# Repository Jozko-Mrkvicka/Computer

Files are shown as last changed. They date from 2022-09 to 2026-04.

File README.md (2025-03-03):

HALUŠKA 9000
============
This is a simulation of very simple 16-bit computer based on logic gates implemented in Matlab/Simulink.
Computer has CPU with 29 instructions, memory consists of 4KB ROM (instructions), 4KB RAM, 1KB video memory, and 4KB of data ROM.
input unit (simple numeric keyboard) and output display (8x16 pixel resolution). To demonstrate
its capabilities there is Snake game hardcoded in ROM.

!!!Please note that this is not the final version, project is still under development!!!

How to run 
----------
- Switch Matlab path to the Computer folder.

- From Matlab command line run the following commands:
    - "Run_Unit_Tests"                            - to check all libraries.
    - "Run_System_Tests"                          - to check high level functionalities.
    - "Compile ROM_Test_UART_Tx"                  - to build binary image of an application.
    - "Flash CODE ROM_Test_UART_Tx_Code 0x0000"   - to program instruction memory from address 0 with the compiled image.
    - "Flash CONST ROM_Test_UART_Tx_Const 0x0000" - to program constant data memory from address 0 with the compiled image.
    - "Computer"                                  - to open computer model.

- In Simulink window click on "play" button to run (or step) simulation.

- From Matlab command line run the following commands:
    - "FrontPanel" - to open front panel debugging/control window.
    - "DataMemory" - to open data memory debugging/control window.

    In file ROM.m there is placed assembly ROM code (firmware) which will be executed after "power on"
(after pressing Run button in Simulink window). This assembly code must be "compiled" to binary
before execution. The assembly code is placed in matlab array in the double format (default matlab format
for storing numeric data). During "compilation" the assembly code is converted to uint16_t format
and can be executed. To compile the code execute ROM.m file from Matlab command line (>> ROM).
You will see compiled binary code in uint16_t format as well as in uint8_t format (MSB/LSB) and also
original assembly code (for your convenience, handy for debugging/crosschecking). 

NOTE: If you forget to "compile" and you try to run the simulation then you will see the following error
message:
    Invalid setting in 'Computer/Memory/32B_ROM_Memory(Addr 0..15)/Byte_00' for parameter 'Value'.
    Caused by:
    Error evaluating parameter 'Value' in 'Computer/Memory/32B_ROM_Memory(Addr 0..15)/Byte_00'
    Undefined function 'RomCode' for input arguments of type 'double'.

After successful "compilation" open the file Computer.slx and press the Run button. Simulation will start.

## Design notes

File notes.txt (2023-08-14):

#############################################
#                   Notes
#############################################
─ ━ │ ┃ ┄ ┅ ┆ ┇ ┈ ┉ ┊ ┋ ┌ ┍ ┎ ┏
┐ ┑ ┒ ┓ └ ┕ ┖ ┗ ┘ ┙ ┚ ┛ ├ ┝ ┞ ┟
┠ ┡ ┢ ┣ ┤ ┥ ┦ ┧ ┨ ┩ ┪ ┫ ┬ ┭ ┮ ┯
┰ ┱ ┲ ┳ ┴ ┵ ┶ ┷ ┸ ┹ ┺ ┻ ┼ ┽ ┾ ┿
╀ ╁ ╂ ╃ ╄ ╅ ╆ ╇ ╈ ╉ ╊ ╋ ╌ ╍ ╎ ╏
═ ║ ╒ ╓ ╔ ╕ ╖ ╗ ╘ ╙ ╚ ╛ ╜ ╝ ╞ ╟
╠ ╡ ╢ ╣ ╤ ╥ ╦ ╧ ╨ ╩ ╪ ╫ ╬ 
╔═══════╤══════╦════════╤═══════╗
║       │      ║        │       ║
╟───────┼──────╫────────┼───────╢
║       │      ║        │       ║
╠═══════╪══════╬════════╪═══════╣
║       │      ║        │       ║
║       │      ║        │       ║
║       │      ║        │       
╚═══════╧══════╩════════╧═══════╝

░▒▓│┤╡╢╖╕╣║╗╝╜╛┐└┴┬├─┼╞╟╚╔╩╦╠═╬╧╨╤╥╙╘╒╓╫╪┘┌█▄▌▐▀ 

#############################################
#              Mrkvicka 9000
#############################################
- Dokumentacia
    - Dokoncit README.
    - Vylestit instrukcie.

    - Mrkvicka 9000 Programmer`s Manual
        - PDF
        - Readme
        - Instructions
        - Demo examples

    - Mrkvicka 9000 Hardware Manual
        - PDF
        - Simulink model

- Hardware:
    - Rozsirit klavesnicu na 128 znakov ASCII (aby sa dala kreslit textova grafika).
    - Pridat na klavesnicu tlacitko SHIFT.
    - Dokoncit obrazovku/terminal.

    - Pridat instrukciu JGT (jump if greater than) kvoli instrukcii CMPI (nie je mozne pouzit instrukciu JLT vo vsetkych pripadoch - operandy sa nedaju prehodit).

    - Pridat timer.

    - Ochrana pamati / error detection:
        - Indikovat chybu ak je viacero kontrolnych signalov do MUXu aktivnych. Vystup poslat na FrontPanel.
        - Detekovat stack overflow/underflow.

    - Zjednodusit architekturu:
        - Nahradit vsetky typy enkoderov pomocou jedneho 16_to_4.
        - Zistit ci by pomohlo keby som nahradil vsetky multiplexory iba pomocou jedneho typu.

- GUI
    - FrontPanel
        - Pridat tlacitka RESET, RUN, STOP, STEP.
    - Pridat Instruction Memory Panel.
    - Pridat Terminal (obrazovka, klavesnica).

- Preprocessor:
    - Zarovnat pravy okraj vygenerovaneho kodu.

- Testy

- Firmware:
    - memcpy()
    - Tetris
    - Snake
    - Hodiny
    - Kalkulacka
    - Textovy editor

    - Faktorial -> Budem musiet ukladat na zasobnik aj navratovu adresu (Return Address Register). Zatial este nemam ziaden return value register pomocou ktoreho by funkcia vracala navratovu hodnotu. Automaticky ukladat return value register.

    - Funkciu ktora dostane argumenty adresa pola a dlzka pola, a vrati sucet prvkov v poli (vytvorit demonstracnu funkciu ktora by dostala parametre z hlavneho programu a vratila by hodnotu. Ide tu o to ze este stale uplne nechapem pracu s funkciami/parametrami). Pridat .data segment/.text segment -> Chyba mi mechanizmus na ukladanie datovych poli do zdrojoveho kodu. Ako nahardcodovat pole cisel do ROM, aby sa neinterpretovali ako instrukcie?? Myslim ze sa na to pouziva sekcia ".data". 

- Ostatne
    - Presunut common library do samostatneho repozitara a pridat .gitsubmodule(s).
    - Skontrolovat v celom projekte ci sa niekde nenachadza string "TODO".

#############################################
#              Mrkvicka 9001
#############################################
- Hardware:
    - Pouzit iba jeden register (accumulator).
        - Usetrim bity v instrukcii.
        - Moznost zvacsit adresovy priestor alebo pridat viac immediate instrukcii.
        - Mensi pocet suciastok.

    - Rozsirit ALU (nasobicka, delicka).
    - Pridat dva specialne 32-bitove registre na aritmeticke operacie.
    - Pridat FPU.

- Naprogramovat Assembler.

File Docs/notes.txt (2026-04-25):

#############################################
#                   Notes
#############################################
Online objednavky:
    - "stackthrough connector", "stackthrough tails"
    - ferrite cores:
        - 1 plane:                                             32 x 32 x 1b
        - 8 planes per bundle:                             8 x 32 x 32 x 1b
        - if low density (10mm between cores) then
            - 2 bundles per cabinet:                   2 x 8 x 32 x 32 x 1b
            - 6 to 8 cabinets per rack:            8 x 2 x 8 x 32 x 32 x 1b = 131,072 cores (16KB)
        - if high density (5mm between cores) then
            - 8 bundles per cabinet:                   8 x 8 x 32 x 32 x 1b
            - 6 to 8 cabinets per rack:            8 x 8 x 8 x 32 x 32 x 1b = 524,288 cores (64KB)

2 ul * countHorizontal * distanceHorizontalBit + distanceHorizontalBetweenBytes + distanceHorizontalBetweenWords

- Decoder_5_to_32 ma cca 230 tranzistorov ~~> 256

─ ━ │ ┃ ┄ ┅ ┆ ┇ ┈ ┉ ┊ ┋ ┌ ┍ ┎ ┏
┐ ┑ ┒ ┓ └ ┕ ┖ ┗ ┘ ┙ ┚ ┛ ├ ┝ ┞ ┟
┠ ┡ ┢ ┣ ┤ ┥ ┦ ┧ ┨ ┩ ┪ ┫ ┬ ┭ ┮ ┯
┰ ┱ ┲ ┳ ┴ ┵ ┶ ┷ ┸ ┹ ┺ ┻ ┼ ┽ ┾ ┿
╀ ╁ ╂ ╃ ╄ ╅ ╆ ╇ ╈ ╉ ╊ ╋ ╌ ╍ ╎ ╏
═ ║ ╒ ╓ ╔ ╕ ╖ ╗ ╘ ╙ ╚ ╛ ╜ ╝ ╞ ╟
╠ ╡ ╢ ╣ ╤ ╥ ╦ ╧ ╨ ╩ ╪ ╫ ╬ 
╔═══════╤══════╦════════╤═══════╗
║       │      ║        │       ║
╟───────┼──────╫────────┼───────╢
║       │      ║        │       ║
╠═══════╪══════╬════════╪═══════╣
║       │      ║        │       ║
║       │      ║        │       ║
║       │      ║        │       
╚═══════╧══════╩════════╧═══════╝

░▒▓│┤╡╢╖╕╣║╗╝╜╛┐└┴┬├─┼╞╟╚╔╩╦╠═╬╧╨╤╥╙╘╒╓╫╪┘┌█▄▌▐▀ 

OOOOOO|DD D|SSS|IIII IIIIIIII IIII

%     % Store full path of the input file.
%     path_and_name = which(filename);

%     % Convert it to string.
%     path_and_name = string(path_and_name);

%     % Replace extension ".m" to ".mat".
%     path_and_name = strrep(path_and_name, ".m", ".mat");

%     save(path_and_name, "CompiledCode");

- Pridat hodiny, napajane samostatne, budu sluzit ako seed do RNG.
- mala pivnica:
    V = 226cm
    D = 210cm
    S = 213cm

#############################################
#              Mrkvicka 9000
#############################################
- Hardware:
    - Zhrnut HW bloky do jedneho CPU, vedla neho datove pamate, vedla nich periferie. 
        - Skusit vymysliet ci by sa z riadiacich signalov nedala vytvorit samostatna control unit. 
    - Pridat reset signal do kazdej pamatovej bunky + reset button. 
    - IRQ_Controller je pripojeny na systemovu databus. Nepaci sa mi to. Myslim ze by mal byt nezavysly, riadeny pomocou specialenej instrukcie. (??)
    - Prerobit MUXy v ALU tak, aby vsetky instrukcie ktore pouzivaju immediate operand, pouzivali ako druhy operand destination register. Teraz je to pomiesane a niektore instrukcie pouzivaju kombinaciu immediate + source_reg, co nedava zmysel (vid CMP vs. CMPI).
    - Carry z ALU do status registra, z neho potom naspat do ALU - tym by sa mali dat scitat bytove polia/int32, int64, ...
    - Prerobit immediate value selection v instruction decoderi. Pozri poznamku v modeli.
    - Vsetky debug outputy ukladat do nejakej struktury, aby sa mi nezobrazoval bordel v matlabovskom workspace.

    - FrontPanel
        - Vyviest vystupnu hodnotu z kazdeho kombinacneho (Mux, Enc, Dec) aj sequencneho obvodu (registre, countre) na front panel (do workspacu).
        - Pridat tlacitka RESET, RUN, STOP, STEP.
        - Error detection:
            - Indikovat chybu ak je viacero kontrolnych signalov do MUXu aktivnych. Vystup poslat na FrontPanel.
            - Indikovat chybu ak je viacero vystupnych signalov z dekodera aktivnych. Vystup poslat na FrontPanel.
            - Stack overflow/underflow detection.
            - Unknown instruction/operand.
            - Kazdy kombinacny (Mux, Enc, Dec) aj sequencny obvod (registre, countre) by mohol mat na front panely vyvedenu svoju vystupnu hodnotu.
            - Built In Test - ku vsetkym subsystemom (s detekciou chyby) priviest false-positive test signal na overenie detekcie chyb.
            - Vyviest error hodnotu z kazdeho MUXu na front panel.

    - Seriovy port:
        - Memory mapped register shift register (Serial_Port_Out).
        - Nahram do neho 1B (parallelne) a on ho automaticky odosle (seriovo, po bitoch).
        - Pridat generovanie start a stop bitov (register bude mat sirku 10 bitov).
        - Nakonfigurovat parametre: baudrate, ...
        - Seriovy port bude pracovat asynchronne na CPU, bude mat vlastny clock.
        - Clock counter na maximalnej baudrate frequencii, bude sa delit pri nizsich baudratoch.
        - Serial_Port_Interrupt pri prijati noveho bajtu.
        - Input port bude 3x (alebo az 5x) sirsi a kazdy prichadzajuci bit sa bude vzorkovat viackrat. Potom sa vypocita spravna hodnota.
        - Ako detekovat ze prichadzaju data???
            - Prijimac je v idle stave (high) a na nakonfigurovanom bitrate vzorkuje Rx vstup. 
            - Vyhodnocuje 5 po sebe iducich vzorkov (1 1 1 1 1) a ked je detekovany start bit (prud vzorkov sa zmeni: 1 1 1 1 1 -> 1 1 1 1 0 -> 1 1 1 0 0 -> 1 1 0 0 0 -> 1 0 0 0 0 -> 0 0 0 0 0) tak zacne prijimane bity zapisovat do input bufferu.
        - Pridat radic serioveho port
            - Serial_Config_Reg
            - Serial_Port_Out
            - Serial_Port_In
        - Spojit sa s RealTermom
        - Vysielanie (Tx).
        - Vymysliet latchovanie interruptu.
        - Vymysliet bufferovanie inputov. 
        - Napisat dokumentaciu.
        - Zistit ako presne sa latchuju interrupty a dopisat ku nim poznamku ze "kazdy interrupt sa zalatchuje okamzite po tom ako vznikol" a nasledne sa sucasne zalatchovane interrupty postupne obsluzia v zavislosti na ich prioritach".
        - Pridat vystupny buffer (8 Bytov), ak su v buffri data (hocico ine okrem 0x00), tak aktivovat interrupt. 
        - Buffer bude namapovany na adresovu zbernicu (posledny byte), citat sa z neho bude stylom "ak interrupt tak citaj until 0". 
        - Ako funguje DMA? Nedalo by sa to pouzit spolu so seriovym portom?

    - Pridat Video subsystem
        - Video RAM ako sucast grafickeho subsystemu. 
        - Pridat ako mem. mapped device 7-segment display + BCD dekoder namiesto obrazovky, len aby som mohol ukoncit projekt. 

- Preprocessor:
    - Zarovnat pravy okraj vygenerovaneho kodu.
    - Naprogramovat linker, aby som mohol buildit kod z viacerych suborov dokopy (aby som mohol na koniec ROMky ulozit kniznicu standartnych funkcii).
    - Pridat oznacenie instrukcie ktora sa prave vykonava (debug mode):
        - Ulozit cely vypis z print_output_values to pola.
        - Zvyraznit dany riadok.
        - Pole pri kazdom kroku prekreslit.
    - Fixnut TODOs.

- GUI
    - FrontPanel
        - Pridat tlacitka RESET, RUN, STOP, STEP.
        - Error detection:
            - Indikovat chybu ak je viacero kontrolnych signalov do MUXu aktivnych. Vystup poslat na FrontPanel.
            - Indikovat chybu ak je viacero vystupnych signalov z dekodera aktivnych. Vystup poslat na FrontPanel.
            - Stack overflow/underflow detection.
            - Unknown instruction/operand.
            - Kazdy kombinacny (Mux, Enc, Dec) aj sequencny obvod (registre, countre) by mohol mat na front panely vyvedenu svoju vystupnu hodnotu.
            - Built In Test - ku vsetkym subsystemom (s detekciou chyby) priviest false-positive test signal na overenie detekcie chyb.
    - Pridat Panel "Instruction Memory".

- Firmware:
    - memcpy()

- Dokumentacia
    - Update README.
    - Vylestit instrukcie.
    - Zjednotit font v poznamkach.
    - Fixnut TODOs.
    - Zjednotit velkosti vsetkych MUXov.
    - Zjednotit velkosti vsetkych systemov.
    - Kombinacne obvody nafarbit na dajaku peknu farbu.

- Project Management:
    - Zaloha na gitlab a bitbucket.
    - Vytvorit branche: Mrkvicka9000, Haluska9000, Haluska9000_1bit.
    - Cez submodule pridat common library, kazdy branch bude ukazovat na inu verziu kniznice (asi bude treba projekt otagovat). 

- Commit Message:

#############################################
#              HALUŠKA 9000
#############################################
- Hardware:
    - von Neumannova architektura
        - Budem moct vytvarat a spustat programy rovno na pocitaci.
        - Programy sa budu dat ukladat/nahravat do/z magnetickej pasky.

    - Prerobit registre:
        - Pridat jeden accumulator register. Bude sluzit ako destination register.
        - Usetrim 3 bity v instrukcnych formatoch ktore pouzivaju destination register.
        - Asi sa zbavim jedneho dekodera ktory vybera destination registre.
        - Budem musiet pridat jednu instrukciu na citanie alebo zapis do/z accumulatora.

    - "Blikaciu" schemu s registrami na hlavnom paneli? tak ako v elektrarni?
    - Priamo nastavovat registre z hlavneho panelu (kvoli debuggingu).
    - Hardwarove breakpointy(??) Nastavil by som adresu na ktorej sa ma prave vykonavany program zastavit.

    - Operacny system:
        - Ochrana pamate (??)
        - Strankovanie / preklad stranok

    - Prerobit architekturu na 1-bit / alebo aspon na 1 byte. Usetrim hradla v multiplexeroch.

    - Prerobit Stack, revertnut zmeny (vratit Stack Pointer). Mal by byt menej hradiel ako ma teraz.

    - Prerobit Muxy tak aby namiesto hradiel NAND pouzivali iba po jednom tranzistore zapojenom ako switch.

    - Ferritova RAM (na prvy krat sa mi to nepodarilo :-()
        - Preprogramovat RAM tak aby hned po precitani zmazala precitane data. Tym sa bude simulovat ferritova pamat.
        - Pridat logiku ktora precitany byte do nej hned nanovo zapise.
        - Pouzit defaultnu RAM zo simulinkovskej kniznice. Ma vyhodu oproti mojej implementacii, ze sa da v jednom clock cyclu precitat aj zapisat tou istou hodnotou (obsahuje delay). Moja implementacia sa sprava ako kombinacny obvod, musim tam mat extra delay ktory dalej sposobuje problemy.

    - Pridat Video subsystem
        - Autoscroll when the screen is full.
        - Each character to be underlined, brightened, blinking or inverse.
        - pouzit jeden riadok bitmapy ako atribut array a nikdy ho nevykreslovat na obrazovku.
        - Presunut charTable.
        - Prerobit charTable na diodovu ROM.
        - Video Controller:
            - register - nova suradnica X
            - register - nova suradnica Y
            - register - aktualna pozicia kurzora x
            - register - aktualna pozicia kurzora y
            - register - data in
            - register - data out
            - register - control
                - read/write on XY bit
                - write on next position bit
            - vsetky registre budu mat input (output) buffer
            - status flag - input buffer full / alebo interrupty??

    - Pridat FPU.
    - Postavit celociselnu nasobicku/delicku
        - Ako samostatne zariadenie pripojene na datovu zbernicu.
        - Ako sequencny obvod.
        - Pracovat s CPU bude asynchronne, komunikacia pomocou prerusena.
        - Bud postavit samostatnu nasobicku a potom nepotrebujem instrukciu SHIFT, alebo nasobit softwarovo (bitshift + scitanie) a potom mi staci SHIFT iba o jeden bit.

    - Periferie:
        - Magneticka paska / harddisk ako externa pamat.
            - Pouzit stary magnetofon.
        - Citacka diernych stitkov (diernej pasky??).
        - Dierovacka stitkov/pasky.

- Compilator:
    - Naprogramovat Assembler.
    - Naprogramovat BASIC alebo pseudoC
    - Pridat lokalne premenne:
        - Hardwarovy stack bude treba prerobit na random access. 
        - Assembler nahradi symbolicky nazov lokalnej premennej jej absolutnou adresou v pamati (zasobnik bude v RAM). Absolutna adresa sa vypocita ako zaciatok zasobniku (pre danu funkciu), ktory sa ulozi pri vstupe do funkcie, plus offset od zaciatku. Na nahradzovanie premennej vypoctom jej adresy asi bude treba pridat novu instrukciu - relativne adresovanie.
        - Priklad:
            char a = 4;
             … sa pri preklade nahradi pomocou …
             STR r0 [sb + 1]   /* Do registra SB sa ulozi hodnota SP pri vstupe do funkcie. */

- GUI:
    - HALUŠKA 9000 (Heuristically programmed ALgorithmic Universal ŠKAtuľa model 9000) 
        - Powered by Jožko Mrkvička / jožko mrkvička inside
    - Pridat Terminal (obrazovka, klavesnica).

- Firmware:
    - Tetris
    - Snake
    - Hodiny
    - Kalkulacka
    - Textovy editor
    - Interpret prikazov / zavadzac programov / kommandlajna

    - Faktorial -> Budem musiet ukladat na zasobnik aj navratovu adresu (Return Address Register). Zatial este nemam ziaden return value register pomocou ktoreho by funkcia vracala navratovu hodnotu. Automaticky ukladat return value register.

    - Funkciu ktora dostane argumenty adresa pola a dlzka pola, a vrati sucet prvkov v poli (vytvorit demonstracnu funkciu ktora by dostala parametre z hlavneho programu a vratila by hodnotu. Ide tu o to ze este stale uplne nechapem pracu s funkciami/parametrami). Pridat .data segment/.text segment -> Chyba mi mechanizmus na ukladanie datovych poli do zdrojoveho kodu. Ako nahardcodovat pole cisel do ROM, aby sa neinterpretovali ako instrukcie?? Myslim ze sa na to pouziva sekcia ".data". 

- Dokumentacia
    - Vsetky subsystemy vlozit do dvoch vrstiev
        - Gate layer
        - System layer.
    - Update README.md.

    - Haluska 9000 User`s Manual
        - Introduction
            - People`s Democratic Republic of East Slovakistan, Jozko Mrkvicka vs. Janko Haluska (Jackil/Hide)
            - "9000 Series makes no mistakes"
            - "A Fistful of Bits", "For a Few Bits More"
        - Hardware
            - Logical Design (Simulink model)
            - Electrical Design
            - Mechanical Design
        - Software
            - Assembler (or Instructions)
            - Standard Library
                - memcpy()
            - Demo Examples
                - Text Editor
                - Calculator
                - Tetris
                - Snake
        - Credentials:
            - fotka celej miestnosti / zaber na obrazovku spoza chrbta / "Fatal Error" -> hlava na stole
            - "People often ask me why do I create such useless bullshits. If I can`t do something more useful? The truth is that I have nothing better to do in my life. I just haven`t figured out if it is good or bad..."

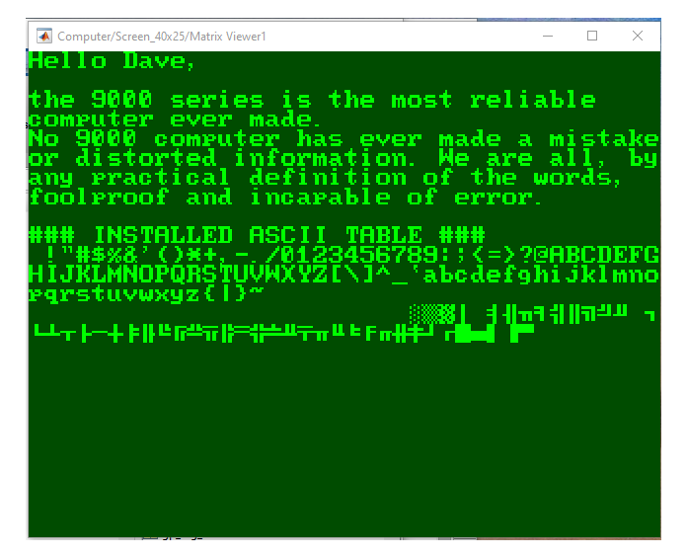
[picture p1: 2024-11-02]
Docs/CharTable_7x7_Example.png

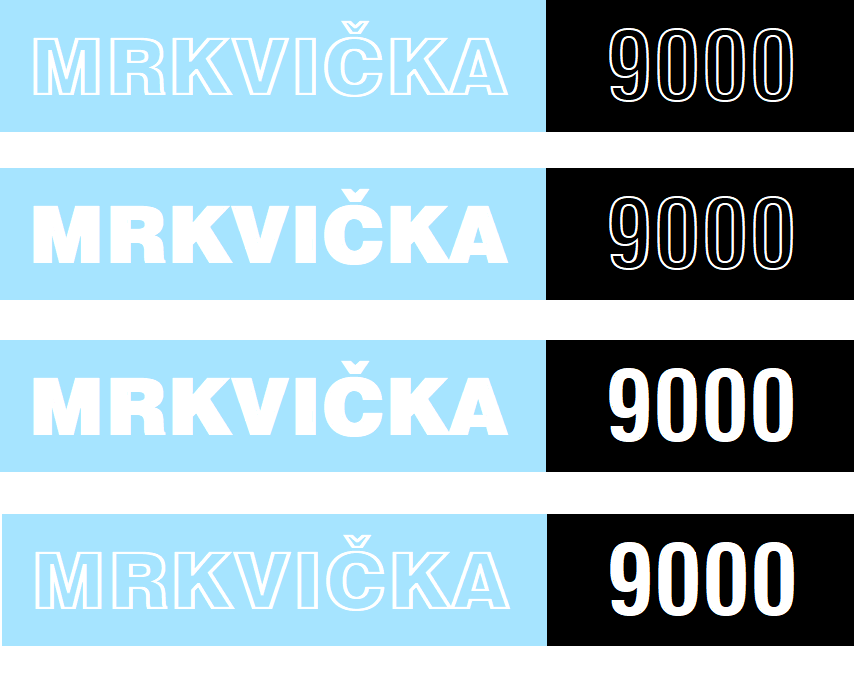
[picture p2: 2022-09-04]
GUI/Mrkvicka9000.png

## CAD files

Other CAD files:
Design_Mechanical/Basement.ipt
Design_Mechanical/Cabinet-FerriteCore.iam
Design_Mechanical/Cabinet-LogicCircuit.iam
Design_Mechanical/CardGuide.ipt
Design_Mechanical/CardGuide/CardGuide#4-inch.ipt
Design_Mechanical/CardGuide/CardGuide#6-inch.ipt
Design_Mechanical/CardGuide/CardGuide#8-inch.ipt
Design_Mechanical/CardGuideArray-4-Inch.iam
Design_Mechanical/CardGuideArray-6-Inch.iam
Design_Mechanical/CardGuideArray-8-Inch.iam
Design_Mechanical/FerriteCoreMem-1KB.iam
Design_Mechanical/GlobalParams.ipt
Design_Mechanical/PCB-FerriteCore.ipt
Design_Mechanical/PCB-FerriteCore/PCB-FerriteCore#Decoder.ipt
Design_Mechanical/PCB-FerriteCore/PCB-FerriteCore#HighPoly.ipt
Design_Mechanical/PCB-FerriteCore/PCB-FerriteCore#LowPoly.ipt
Design_Mechanical/PCB.ipt
Design_Mechanical/PCB/PCB#LogicCircuit.ipt
Design_Mechanical/PCB/PCB#SwitchPanel.ipt
Design_Mechanical/Panel-Mprom.iam
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

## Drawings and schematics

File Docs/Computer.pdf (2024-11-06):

General_Purpose_Registers Instruction_Decoder
Instruction Memory | ALU

# Data Memory

General_Purpose_Timer_16bit

# Stack

Keyboard_IBM437

# Stack

# Instruction Memory

CYAN COLOR means that block contains sequential logic. BLUE COLOR means that line represents control signal. GREEN COLOR means that line represents address.

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
.0xFFFF> | Data Memory

# CMD_SET_START_VALUE - Address 0x0001 - Data <0x0000..0xFFFF>

# CMD_RESET - Address 0x0002 - Data N/A

# CMD_MODE - Address 0x0003 - Data 0x0000 (One Shot) 0x0001 (Free Run)

# CMD_RUN - Address 0x0004

- Data | 0x0000 (Halt) 0x0001 (Run)
Instruction Decoder | GP Timer

# Keyboard

Note: In physical implementation, this multiplexer will not be needed.

# TODO: Ja si myslim ze format 0 by mal pouzivat iba unsigned immediate. Teraz pouziva

signed (imm formatu 0 sa vzdy pouziva ako adresa a adresa nikdy nemoze byt zaporna).

# TODO: Nahradit pomocou Byte_Mux pretoze datova pamat je clenena po bajtoch. ALU

# Registers

# AuxALU

# Test_Outputs

A(2B) B(2B) | A+B(2B) Carry(1b)

# Instruction_ROM (0x000 .. 0xFFF)

Enable(1b) Addr_4(1b) Addr_3(1b) Addr_2(1b) Addr_1(1b) Addr_0(1b)

Sel_31(1b) Sel_30(1b) Sel_29(1b) Sel_28(1b) Sel_27(1b) Sel_26(1b) Sel_25(1b) Sel_24(1b) Sel_23(1b) Sel_22(1b) Sel_21(1b) Sel_20(1b) Sel_19(1b) Sel_18(1b) Sel_17(1b) Sel_16(1b) Sel_15(1b) Sel_14(1b) Sel_13(1b) Sel_12(1b) Sel_11(1b) Sel_10(1b) Sel_09(1b) Sel_08(1b) Sel_07(1b) Sel_06(1b) Sel_05(1b) Sel_04(1b) Sel_03(1b) Sel_02(1b) Sel_01(1b) Sel_00(1b)

Enable(1b) Addr_4(1b) Addr_3(1b) Addr_2(1b) Addr_1(1b) Addr_0(1b)

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

# Enable(1b) Addr_4(1b) Addr_3(1b) Addr_2(1b) Addr_1(1b) Addr_0(1b)

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

# Enable(1b) Addr_4(1b) Addr_3(1b) Addr_2(1b) Addr_1(1b) Addr_0(1b)

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

# Data(1000B) Screen_40x25

# CLK Random_Number(2B) Linear_Feedback_Shift_Register_15bit (random number generator)

undef Down

_

]}

## Zz Ww

Write Sel_1(1b) Sel_0(1b) Data_1(2B) Data_0(2B) | Data(2B)

Sel_7(1b) Sel_6(1b) Sel_5(1b) Sel_4(1b) Sel_3(1b) Sel_2(1b) Sel_1(1b) Sel_0(1b) Data_7(2B) Data_6(2B) Data_5(2B) Data_4(2B) Data_3(2B) Data_2(2B) Data_1(2B) Data_0(2B)

Data(2B)

# Sel_3(1b) Sel_2(1b) Sel_1(1b) Sel_0(1b) Data_3(2B) Data_2(2B) Data_1(2B) Data_0(2B)

Data(2B)

Sel_1(1b) Sel_0(1b) Data_1(2B) Data_0(2B) | Data(2B)
Sel_1(1b) Sel_0(1b) Data_1(2B) Data_0(2B) | Data(2B)
Sel_1(1b) Sel_0(1b) Data_1(2B) Data_0(2B) | Data(2B)
Sel_1(1b) Sel_0(1b) Data_1(2B) Data_0(2B) | Data(2B)

# uint_to_bus2

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

Sel(1b)

In(2B) | Out(2B) Sel(1b)
In(2B) | Out(2B)

Sel(1b)
In(2B) Out(2B)

Xx

Sel(1b)
In(2B) | Out(2B) Sel(1b)
In(2B) | Out(2B) Sel(1b)
In(2B) | Out(2B)

Sel(1b)
In(2B) Out(2B)

Sel(1b)
In(2B) Out(2B)

Sel(1b)
In(2B) | Out(2B)
Select(1b) Write(1b) Data(2B) CLK | DataOut(2B) Word_12
Select(1b) Write(1b) Data(2B) CLK | DataOut(2B) Word_06
Select(1b) Write(1b) Data(2B) CLK | DataOut(2B) Word_02

Vv Uu

Sel(1b)
In(2B) Out(2B)

# Stack Debug

# Shift

# Set

Sel_1(1b) Sel_0(1b) Data_1(2B) Data_0(2B) | Data(2B) Select_Data

# Sel_3(1b) Sel_2(1b) Sel_1(1b) Sel_0(1b) Data_3(2B) Data_2(2B) Data_1(2B) Data_0(2B)

# Data(2B) Select_Address

Rr

# Video_RAM (0x000 .. 0x3FF)

Sel(1b)
In(2B) Out(2B)

Pp

Sel(1b)
In(2B) Out(2B)

Oo2

Oo
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

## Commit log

2018-11-24 - Added new file - Common_Library.mdl. In this library there will be stored common parts like encoders, adders, multiplexers...
    - Common parts from Computer_Library.mdl were shifted to Common_Library.mdl.
2019-02-03 Computer.mdl - MOV and ADD instructions added (full fuctionality) - ALU stores its results into GP registers - GP registers simplified a bit
    Common_Library.mdl
    - fixed bug in 4_to_2_Encoder
    Computer_Library.mdl
    - deleted output register from ALU (ALU is now only a combination circuit)
2019-05-05 - New instruction format created. - Assembler preprocessor adjusted to new format.
2019-06-30 - New preprocesor feature - labels instead od physical addresses in assembler code. - Keyboard subsystem introduced.
2021-07-04 - Added new block Encoder_64_to_6. - The keyboard module finished. Keyboard has now 64 characters and it also contains latches for storing pressed key. - Instruction Get Char (GCH) removed. This inst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
2021-10-03 - Graphic subsystem deleted. Now the graphic memory is mapped directly to address bus. It can be used in both ways, as a normal RAM and also as a dedicated video memory. - Instructions GPX, SPX0 and 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
2021-11-01 Clean up, wires rearranged a bit.
2021-12-05 - The Computer_Library renamed to Miscellaneous and moved to the Common_Lib folder. - Command bus selectors replaced with single one which can be manually configured. - Manually configured address se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
2022-04-30 Address selectors moved one level up (from memory blocks and from periferal devices).
2022-05-29 Added dedicated constant data ROM memory. It is attached to data bus.
2022-05-29 - New assembler in developement. - The Sublime Text syntax highlight rules created for new assembler.
2022-06-05 Assembler updated - the data section is now parsed and checked.
2022-06-06 Assembler updated. Couple of bugs fixed. Couple of new functions added.
2022-06-12 I have started to write the Assembler once again from scratch. New iteration is stored in the file Assembler2.m.
2022-06-17 New Assembler functions added to test and parse the .DATA section.
2022-06-18 New Assembler functions added to test and parse the .CONST section.
2022-07-03 New Assembler functions added to parse the instruction formats 0 and 3 in the .TEXT section.
2022-07-03 Assembler updated to check instruction formats 1 and 2.
2022-09-04 The instruction bus encoder and the instruction bus selectors replaced with the simulink bus (bus creator and bus selectors).
2023-07-09 - New instructions added (STLI, STUI, LDLI, LDUI and OFST). - Instructions LOADL, LOADU, STOREL and STOREU renamed to LDL, LDU, STL and STU.
2023-07-09 Couple of bugs fixed, GUI updated, tests updated.
2023-08-20 - New Encoder_128_to_7 added. - Computer formatting polished.
2024-10-21 - The encoders library moved to the common library. - Unused subsystems from the miscellaneous library moved to new Garbage library.
2024-10-23 Data bus and devices connected to it reworked.
2024-10-24 Stack polished, ready for printing.
2024-10-25 - ASCII characters polished. - Keyboard reworked, polished and ready for printing.
2024-10-27 - Keyboard buttons wired to new keyboard subsystem. - Preprocessor and system tests updated with hexadecimal and binary constants.
2024-10-30 Instruction decoder polished and ready for printing.
2024-10-31 ALU polished and ready for printing.
2024-10-31 Registers polished and ready for printing.
2024-11-02 Interrupt request handler logic added.
2024-11-05 - General Purpose Timer added. - Timer system test added.
2024-11-06 Delay timer added to the keyboard interrupt logic. System test adapted.
2024-11-08 - Interrupt controler created. Multiple interrupts can now occur in parallel. - New system tests added to check new interrupt functionality.
2024-11-08 - Interrupt Control polished and ready for printing. - Logo added.
2025-03-01 - New folder Design_Mechanical added. - Initial mechanical model of the computer created.
    [Basement.ipt, Cabinet-FerriteCore.iam, Cabinet-LogicCircuit.iam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]
2025-03-01 Prototypes of the video memory and the serial port added.
2025-03-02 - UART Transmitter partially integrated to Computer. - Parameter handling in the Flash script updated. - New UART Transmitter system test added.
2025-03-03 - Preprocessor, Flash script and Compile script reworked: - It is possible to use the BYTE datatype. - It is possible to store constant data to ROM memory. - The UART Tx system test reworked, it keep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
2026-05-02 - Unfinished CPU wiring update.
